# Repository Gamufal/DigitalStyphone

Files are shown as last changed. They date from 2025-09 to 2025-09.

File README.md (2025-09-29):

# Digital Stylophone

A microcontroller-based stylophone with recording and playback capabilities, built around the Raspberry Pi Pico. This project reimagines the classic analog instrument with modern digital features, including an OLED display and non-volatile memory for storing recorded tracks.

## Demo

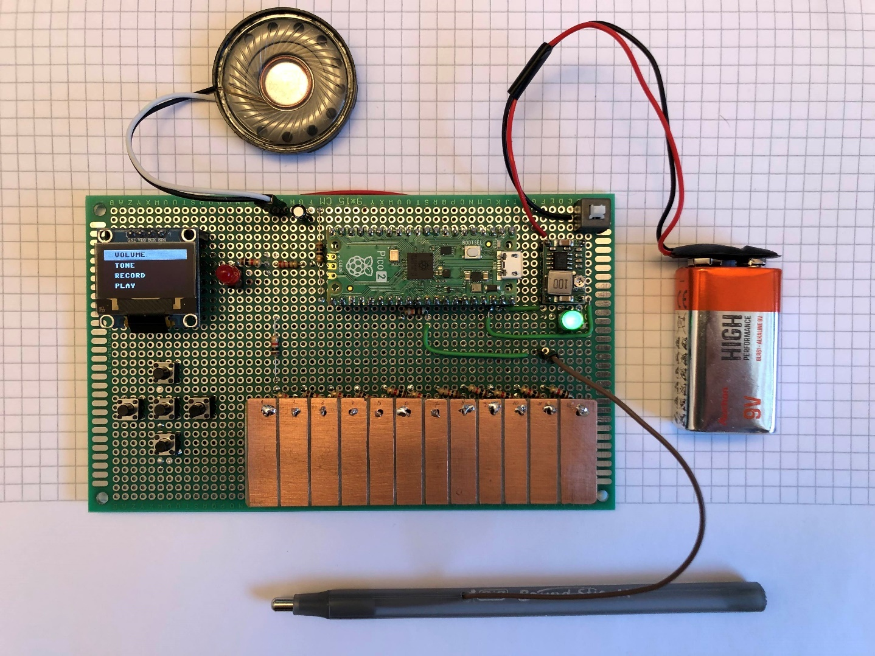
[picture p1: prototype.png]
Digital Stylophone


## Features

*   **Sound Generation:** Produces a square wave tone with a classic synthesizer sound.
*   **Multiple Octaves:** Three selectable octaves (low, middle, high).
*   **Volume Control:** Adjustable volume with 8 levels.
*   **Recording & Playback:** Record, save, and play back musical sequences.
*   **Persistent Memory:** Saves the recorded track and user settings (volume, octave) to a `settings.json` file on the device.
*   **OLED Display Interface:** A 128x64 SSD1306 OLED screen provides a menu-based interface for all functions.
*   **Tactile Controls:** 5-button navigation for intuitive menu control.
*   **Portable Design:** Powered by a 9V battery for on-the-go use.
*   **Raspberry Pi Pico Core:** Utilizes a Raspberry Pi Pico for all processing and hardware control.

## Hardware

### Components

| Component | Quantity |
|---|---|
| Raspberry Pi Pico | 1 |
| 5mm LED | 2 |
| 10Ω Resistor (1/4W) | 1 |
| 1kΩ Resistor (1/4W) | 21 |
| 10kΩ Resistor (1/4W) | 1 |
| 10uF Capacitor | 1 |
| 0.96" OLED Display | 1 |
| LM2596 Step-down Converter | 1 |
| 6x6mm Tactile Switch | 5 |
| Female Pin Headers | 5 |
| Latching Switch | 1 |
| 9V Battery | 1 |
| 1W 8Ohm Speaker | 1 |

### Schematic

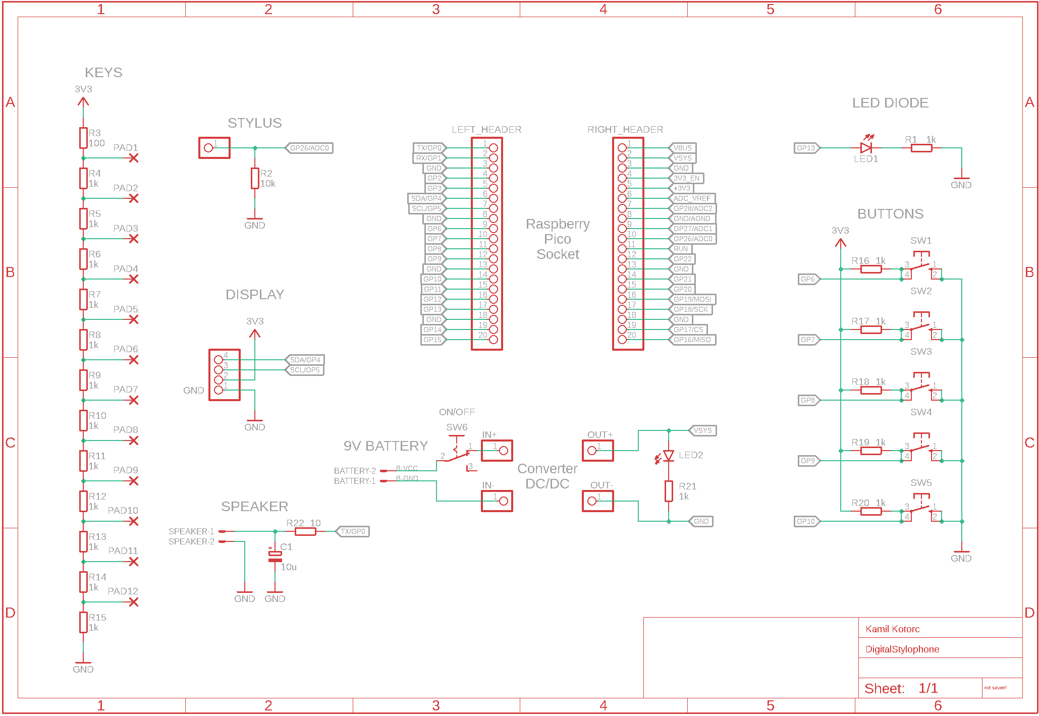
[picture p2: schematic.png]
Schematic


### PCB Design

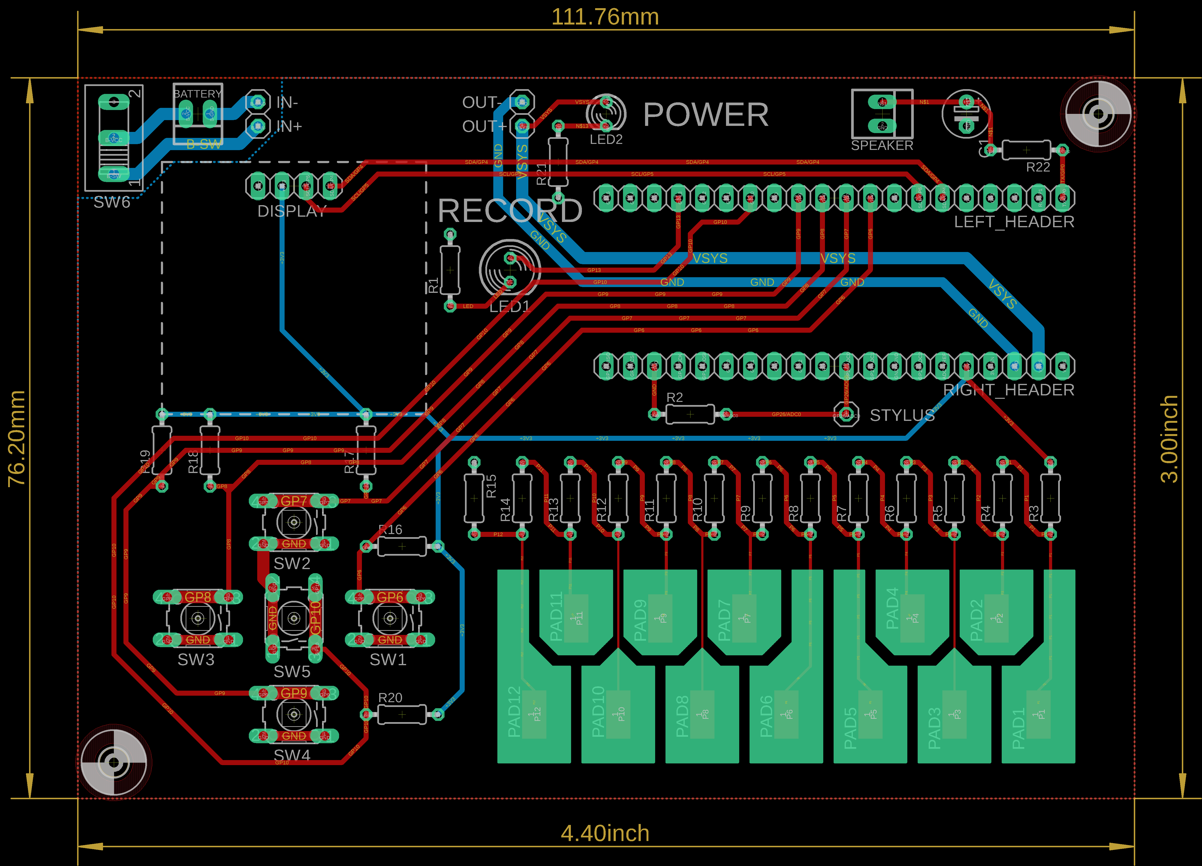
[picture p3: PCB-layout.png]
PCB Layout

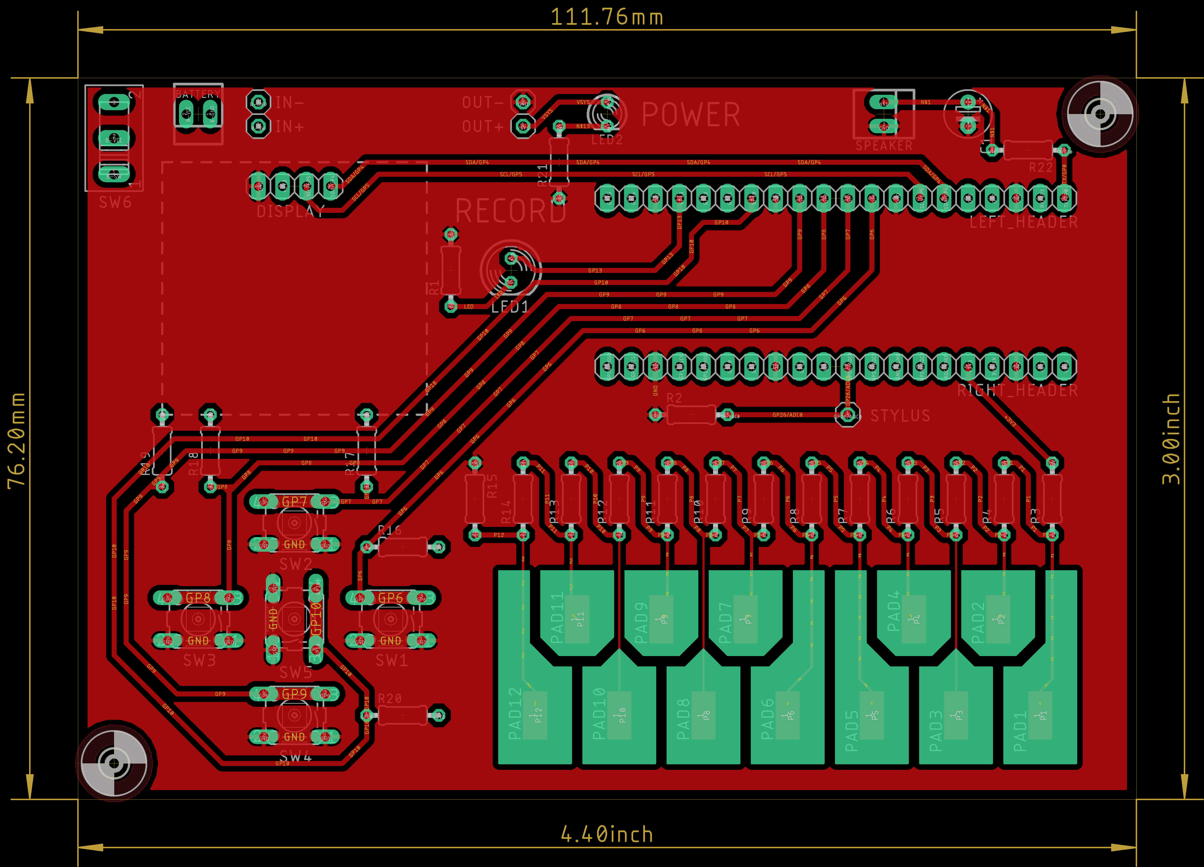
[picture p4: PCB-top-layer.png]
PCB_Top

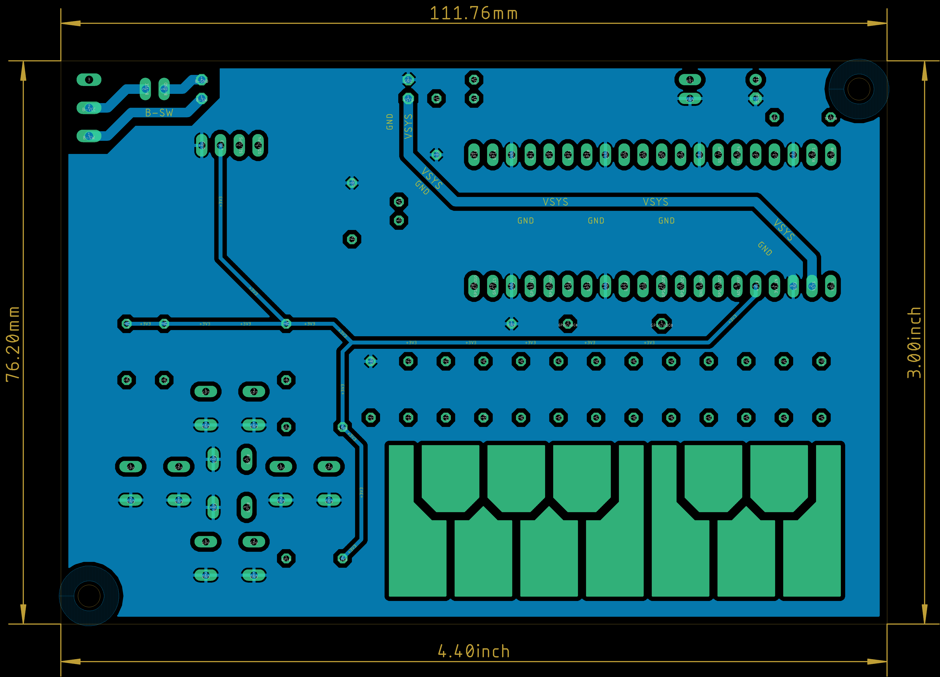
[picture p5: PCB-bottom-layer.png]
PCB_Bottom


### Manufacture Preview

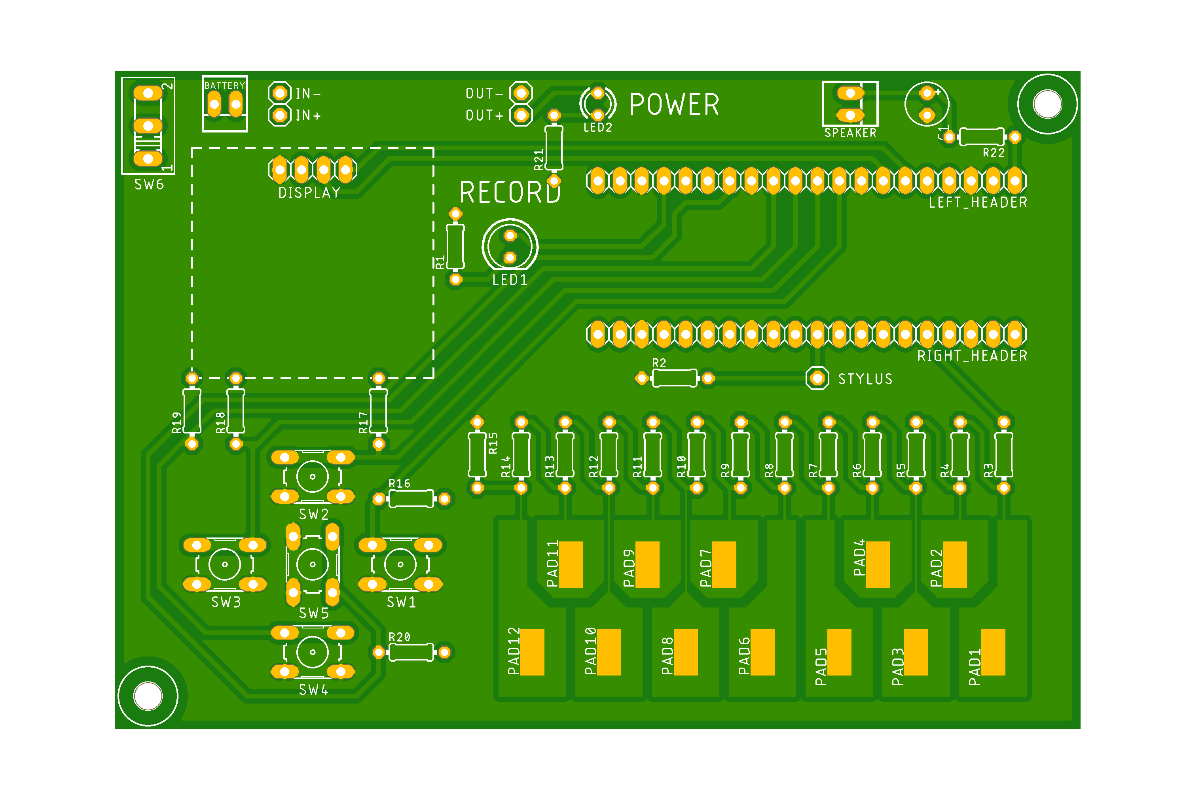
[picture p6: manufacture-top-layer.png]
Manufacture Top

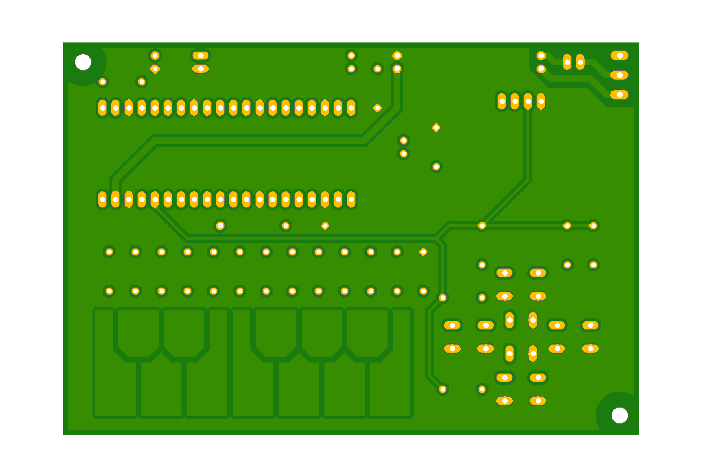
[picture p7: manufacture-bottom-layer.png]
Manufacture Bottom


### 3D Housing Model

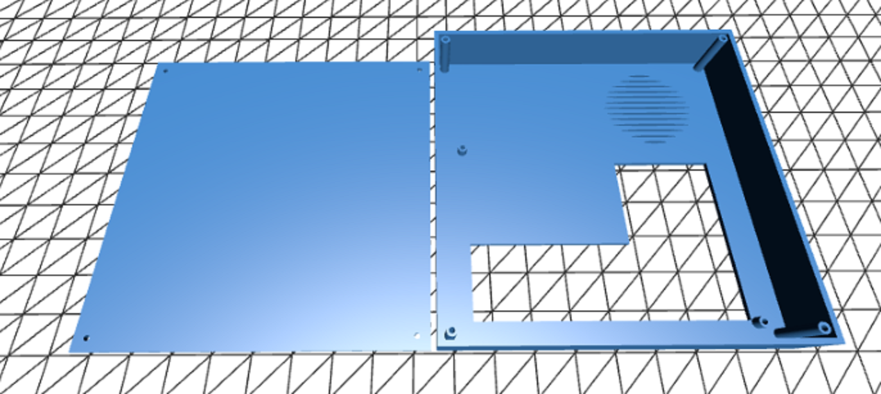
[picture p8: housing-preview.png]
Housing

A 3D-printed enclosure can also be made for the device. A model of the enclosure has been prepared for this purpose, and it is available as the `housing.stl` file.

## Software

### How it Works

The device is controlled by a MicroPython script (`main.py`) running on the Raspberry Pi Pico.

*   **Sound Generation:** The stylus's position on the resistive keyboard is read as an analog value by the Pico's ADC (Analog-to-Digital Converter). This value is then mapped to a specific musical note frequency. The sound is generated using PWM (Pulse Width Modulation) sent to a 1W speaker.

*   **UI & Menu:** A menu-driven interface is displayed on the 128x64 OLED screen. The user navigates the menu using a 5-button keypad. The available options are Volume, Tone (Octave), Record, and Play.

*   **Recording & Playback:** The recording function captures a sequence of notes and their timings. It records pairs of `(frequency, timestamp)` to a list. The playback function iterates through the recorded list, playing back the notes with the correct timing.

*   **Persistence:** The recorded song, as well as the volume and tone settings, are saved to a `settings.json` file in the Pico's flash memory. This allows the device to retain settings and recordings between power cycles.

### Installation

1.  **Install MicroPython:** If you haven't already, install MicroPython on your Raspberry Pi Pico. You can find the official instructions [here](https://www.raspberrypi.com/documentation/microcontrollers/micropython.html).

2.  **Install `ssd1306.py`:** The OLED display requires the `ssd1306.py` library. You can find it [here](https://github.com/micropython/micropython/blob/master/drivers/display/ssd1306.py) and save it to your Pico.

3.  **Upload the Software:** Copy the `main.py` file to your Raspberry Pi Pico. The easiest way to do this is by using an IDE like [Thonny](https://thonny.org/), which has a simple interface for managing files on a MicroPython device.

## User Guide

### Controls

| Control | Function |
|---|---|
| Up/Down Buttons | Navigate through the main menu. |
| Left/Right Buttons | Decrease/increase the volume or tone (octave). |
| OK Button | Select a menu option; start/stop recording or playback. |
| Stylus | Play notes by touching the corresponding keys. |

### Operation

1.  **Power On:** Connect a 9V battery and flip the power switch. The green LED will light up, and the main menu will appear on the OLED display.
2.  **Play Music:** Simply touch the stylus to any of the metal keys to play a note.
3.  **Navigate Menu:** Use the **Up** and **Down** buttons to highlight a menu option.
4.  **Select Option:** Press the **OK** button to enter the selected menu (Volume, Tone, Record, or Play).
5.  **Adjust Volume/Tone:** In the Volume or Tone menus, use the **Left** and **Right** buttons to make adjustments. Press **Up** or **Down** to exit and save.
6.  **Record:** Select "RECORD" from the main menu and press **OK**. Press **OK** again to start recording. The red LED will blink. Play your tune, and press **OK** to stop. The recording will be saved automatically.
7.  **Playback:** Select "PLAY" from the main menu and press **OK**. Press **OK** again to start playback of the last recorded track. The red LED will stay lit during playback.

## Troubleshooting

| Symptom | Possible Cause | Suggested Solution |
|---|---|---|
| Screen works, but the green power LED is off. | The green LED is burnt out. | Replace the green LED. |
| The green power LED is on, but the screen is blank. | The OLED display is damaged or disconnected. | Check the display's connections. If the problem persists, replace the display module. |
| Nothing works (no screen, no LEDs). | The 9V battery is dead. | Replace the 9V battery. |
| The screen and LEDs work, but there is no sound. | The speaker is damaged or disconnected. | Check the speaker wiring. If the problem persists, replace the speaker. |

## Future Improvements

*   **Enhanced Sound Engine:**
    *   Add a vibrato effect using a Low-Frequency Oscillator (LFO).
*   **Connectivity:**
    *   Add MIDI output via USB, allowing the stylophone to function as a MIDI controller.
*   **Code Refinements:**
    *   Refactor the code for better efficiency, especially the recording and display update logic.

## License

This project is licensed under the MIT License. See the `LICENSE` file for details.

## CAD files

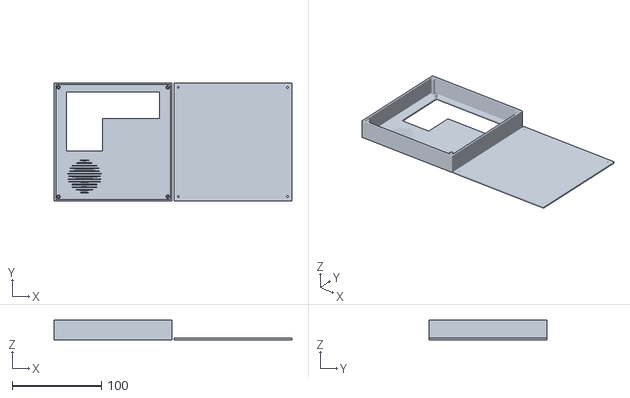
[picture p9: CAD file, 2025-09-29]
housing.stl
266.0 x 132.0 x 22.0

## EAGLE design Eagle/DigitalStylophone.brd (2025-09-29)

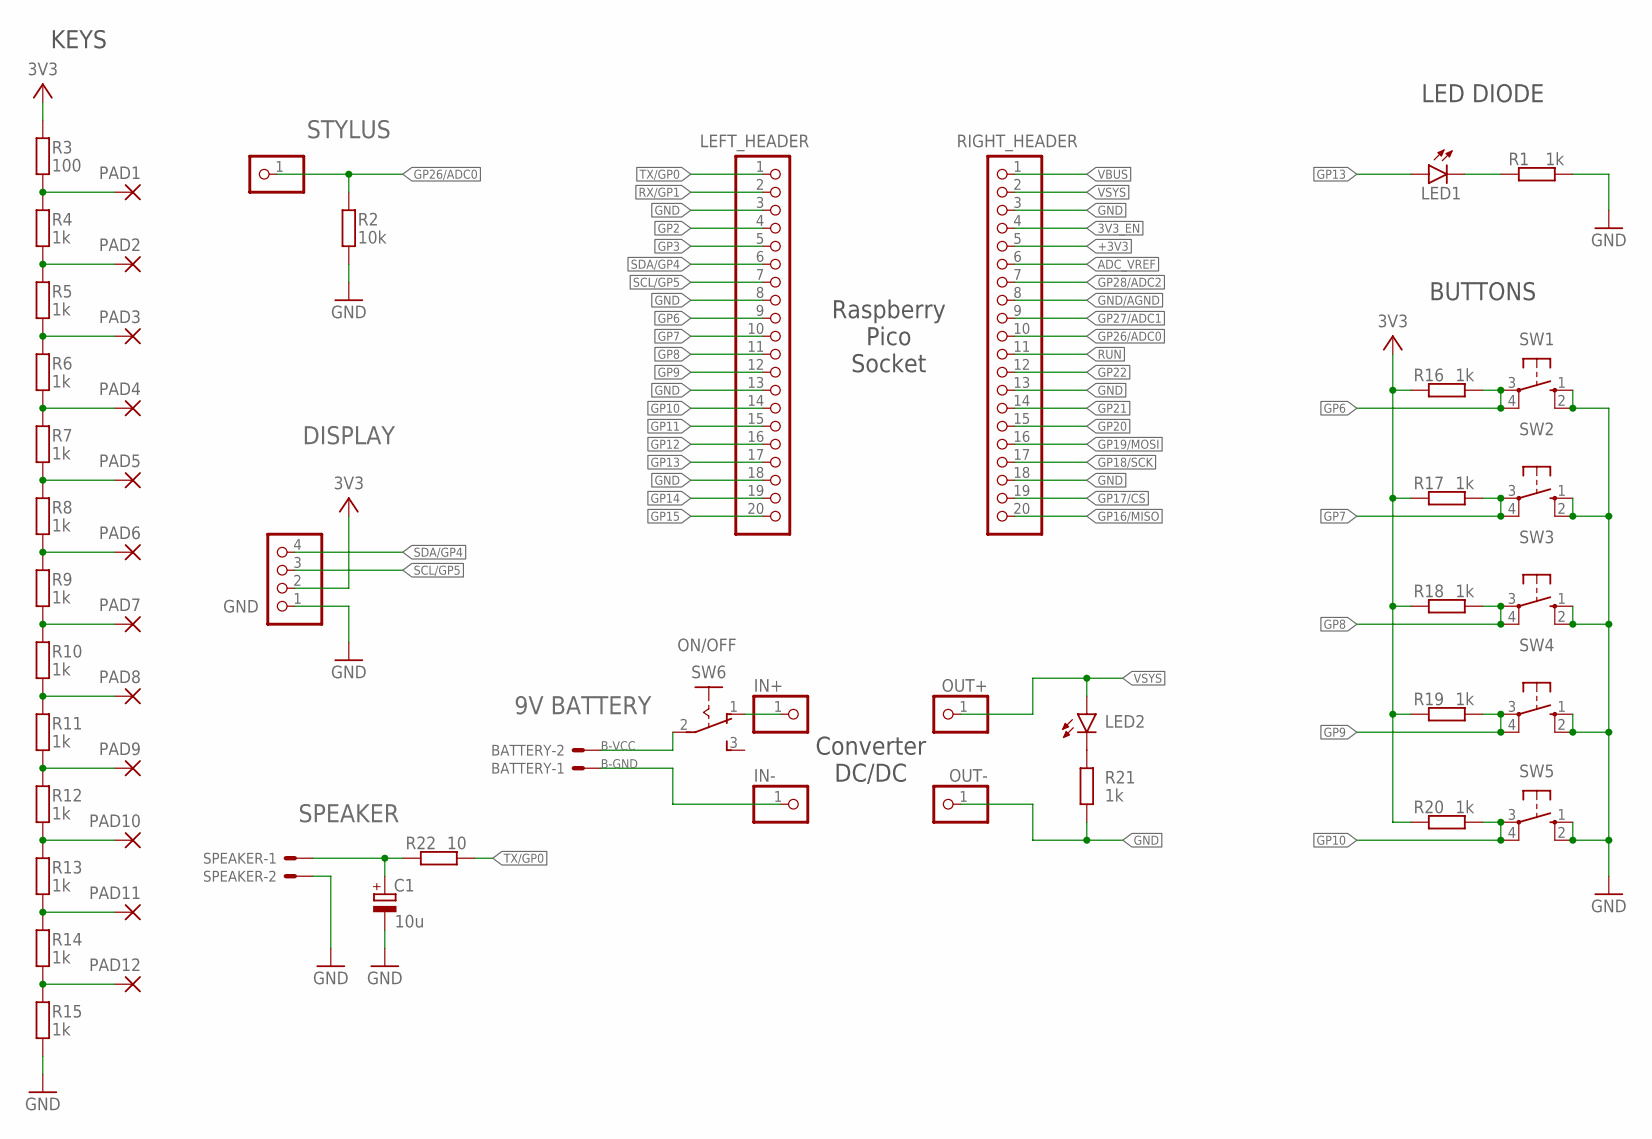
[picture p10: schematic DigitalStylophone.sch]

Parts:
BATTERY: 9V BATTERY; 22-23-2021
C1: 10u; E2,5-5
DISPLAY: GND; 1X04
IN+: PINHD-1X1; 1X01
IN-: PINHD-1X1; 1X01
LED1: LED5MM
LED2: LED3MM
LEFT_HEADER: PINHD-1X20; 1X20
OUT+: PINHD-1X1; 1X01
OUT-: PINHD-1X1; 1X01
PAD1, PAD2, PAD3, PAD4, PAD5, PAD6, PAD7, PAD8, PAD9, PAD10, PAD11, PAD12: SMD5; SMD2,54-5,08
R1, R4, R5, R6, R7, R8, R9, R10, R11, R12, R13, R14, R15, R16, R17, R18, R19, R20, R21: 1k; 0204/7
R2: 10k; 0204/7
R3: 100; 0204/7
R22: 10; 0204/7
RIGHT_HEADER: PINHD-1X20; 1X20
SPEAKER: SPEAKER; 22-23-2021
STYLUS: PINHD-1X1; 1X01
SW1, SW2, SW3, SW4, SW5: 10-XX; B3F-10XX
SW6: ON/OFF; 255SB

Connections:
3V3_EN: RIGHT_HEADER.4
+3V3: DISPLAY.2, R3.2, R16.2, R17.2, R18.2, R19.2, R20.2, RIGHT_HEADER.5
ADC_VREF: RIGHT_HEADER.6
B-GND: BATTERY.1, IN-.1
B-SW: IN+.1, SW6.1 (O)
B-VCC: BATTERY.2, SW6.2
GND: C1.-, DISPLAY.1, LEFT_HEADER.3, LEFT_HEADER.8, LEFT_HEADER.13, LEFT_HEADER.18, OUT-.1, R1.1, R2.1, R15.1, R21.1, RIGHT_HEADER.3, RIGHT_HEADER.13, RIGHT_HEADER.18, SPEAKER.2, SW1.1 (S), SW1.2 (S1), SW2.1 (S), SW2.2 (S1), SW3.1 (S), SW3.2 (S1), SW4.1 (S), SW4.2 (S1), SW5.1 (S), SW5.2 (S1)
GND/AGND: RIGHT_HEADER.8
GP2: LEFT_HEADER.4
GP3: LEFT_HEADER.5
GP6: LEFT_HEADER.9, R16.1, SW1.3, SW1.4 (P1)
GP7: LEFT_HEADER.10, R17.1, SW2.3, SW2.4 (P1)
GP8: LEFT_HEADER.11, R18.1, SW3.3, SW3.4 (P1)
GP9: LEFT_HEADER.12, R19.1, SW4.3, SW4.4 (P1)
GP10: LEFT_HEADER.14, R20.1, SW5.3, SW5.4 (P1)
GP11: LEFT_HEADER.15
GP12: LEFT_HEADER.16
GP13: LED1.A, LEFT_HEADER.17
GP14: LEFT_HEADER.19
GP15: LEFT_HEADER.20
GP16/MISO: RIGHT_HEADER.20
GP17/CS: RIGHT_HEADER.19
GP18/SCK: RIGHT_HEADER.17
GP19/MOSI: RIGHT_HEADER.16
GP20: RIGHT_HEADER.15
GP21: RIGHT_HEADER.14
GP22: RIGHT_HEADER.12
GP26/ADC0: R2.2, RIGHT_HEADER.10, STYLUS.1
GP27/ADC1: RIGHT_HEADER.9
GP28/ADC2: RIGHT_HEADER.7
LED: LED1.K (C), R1.2
unnamed: C1.+, R22.2, SPEAKER.1
unnamed: LED2.K (C), R21.2
P1: PAD1.1, R3.1, R4.2
P2: PAD2.1, R4.1, R5.2
P3: PAD3.1, R5.1, R6.2
P4: PAD4.1, R6.1, R7.2
P5: PAD5.1, R7.1, R8.2
P6: PAD6.1, R8.1, R9.2
P7: PAD7.1, R9.1, R10.2
P8: PAD8.1, R10.1, R11.2
P9: PAD9.1, R11.1, R12.2
P10: PAD10.1, R12.1, R13.2
P11: PAD11.1, R13.1, R14.2
P12: PAD12.1, R14.1, R15.2
RUN: RIGHT_HEADER.11
RX/GP1: LEFT_HEADER.2
SCL/GP5: DISPLAY.3, LEFT_HEADER.7
SDA/GP4: DISPLAY.4, LEFT_HEADER.6
TX/GP0: LEFT_HEADER.1, R22.1
VBUS: RIGHT_HEADER.1
VSYS: LED2.A, OUT+.1, RIGHT_HEADER.2

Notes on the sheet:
Raspberry Pico Socket
KEYS
LED DIODE
BUTTONS
Converter DC/DC

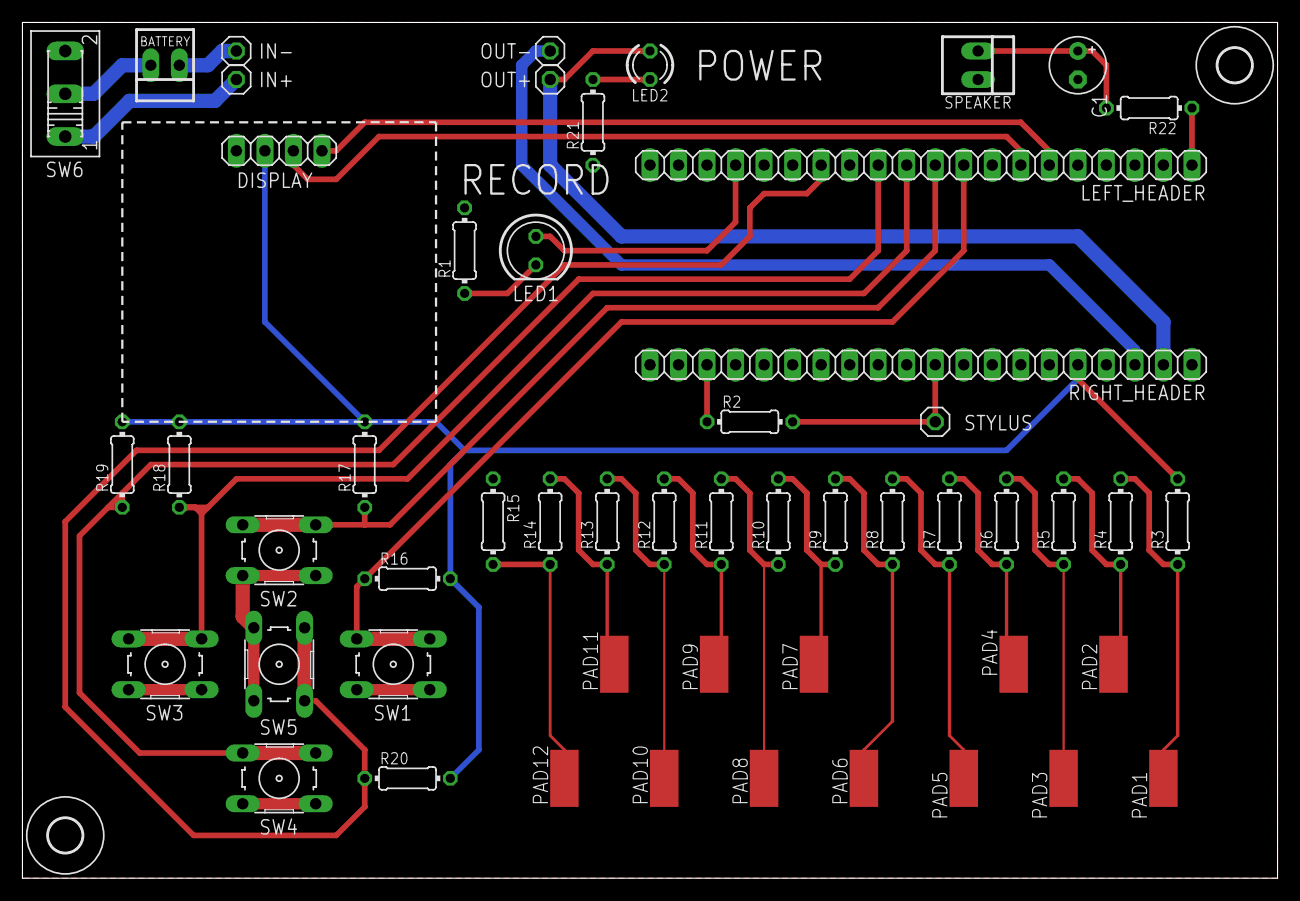
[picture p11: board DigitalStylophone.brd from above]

Board: 2 copper layers, 111.8 x 76.2 mm, 55 parts (0 on the bottom side), 31 nets.

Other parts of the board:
U$1, U$2: 3,0

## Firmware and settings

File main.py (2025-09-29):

# Software for Digital Stylophone project
# Made by Gamufal
# Version: 25.9.1

from machine import Pin, ADC, I2C, PWM
import ssd1306
import json
from time import sleep, time, ticks_ms, ticks_diff

# Initialization of OLED Display (128x64)
i2c = I2C(0, sda=Pin(4), scl=Pin(5), freq=400000)
display = ssd1306.SSD1306_I2C(128, 64, i2c)

# LED diode initialization
led = Pin(13, Pin.OUT)

# Buttons initialization 
btn_down  = Pin(6,  Pin.IN, Pin.PULL_UP)
btn_up    = Pin(8,  Pin.IN, Pin.PULL_UP)
btn_right = Pin(7,  Pin.IN, Pin.PULL_UP)
btn_left  = Pin(9,  Pin.IN, Pin.PULL_UP)
btn_ok    = Pin(10, Pin.IN, Pin.PULL_UP)

# ADC Initialization for stylus 
adc = ADC(Pin(26))
adc_thresholds = [4500, 9000, 13000, 17000, 20000, 24000, 29000, 34000, 39000, 46000, 54000, 64000]

# PWM Initialization for the speaker
spk = PWM(Pin(16))
spk.duty_u16(0)

# Three sets of notes:
lower_octave  = [131, 139, 147, 156, 165, 175, 185, 196, 208, 220, 233, 247]
middle_octave = [261, 277, 293, 311, 329, 349, 369, 392, 415, 440, 466, 493]
higher_octave = [523, 554, 587, 622, 659, 698, 739, 784, 830, 880, 932, 987]

# Global settings
volume = 4   # 1-8
tone = 2     # 1-3
recording = []  # (freq, timestamp), ...

# Saves a single setting to a JSON file
def save_single_setting(key, value):
    try:
        with open("settings.json", "r") as f:
            settings = json.load(f)
    except (OSError, ValueError):
        settings = {}
    settings[key] = value
    with open("settings.json", "w") as f:
        json.dump(settings, f)
    print(f"Saved {key}: {value}")

# Loads saved settings from a JSON file
def load_settings():
    global volume, tone, recording
    try:
        with open("settings.json", "r") as f:
            settings = json.load(f)
            volume = settings.get("volume", 4)
            tone = settings.get("tone", 2) 
            recording = settings.get("recording", [])  
        print("Settings loaded!")
    except Exception as e:
        print("No settings found, using defaults.", e)

# Returns the index of the note based on the ADC value
def get_note_index(adc_val):
    idx = -1
    for i in range(len(adc_thresholds)):
        if adc_val >= adc_thresholds[i]:
            idx = i
        else:
            break
    return idx if idx != -1 else None

# Retrieves the note frequency from the index and currently selected octave
def get_note_from_index(idx):
    global tone
    if tone == 1:
        return lower_octave[idx]
    elif tone == 2:
        return middle_octave[idx]
    elif tone == 3:
        return higher_octave[idx]

# Updates the speaker output in real time based on the ADC reading
def update_live_audio():
    adc_val = adc.read_u16()
    idx = get_note_index(adc_val)
    if idx is not None:
        freq = get_note_from_index(idx)
        spk.freq(freq)
        spk.duty_u16(volume * 4096)
    else:
        spk.duty_u16(0)

# Displays the main menu
def display_menu(selected_item):
    menu_items = ["VOLUME", "TONE", "RECORD", "PLAY"]
    display.fill(0)
    for i, item in enumerate(menu_items):
        y = i * 16
        if i == selected_item:
            display.fill_rect(0, y, 128, 16, 1)  
            display.text(item, 16, y + 4, 0)      
        else:
            display.text(item, 16, y + 4, 1)      
    display.show()

# Handles volume adjustment
def volume_menu():
    global volume
    display.fill(0)
    display.text("VOLUME", 16, 30, 1)
    display.text(str(volume), 104, 30, 1)
    bar_width = int(volume * 96 / 8)
    display.fill_rect(16, 45, bar_width, 10, 1)
    display.show()
    while True:
        update_live_audio()
        if btn_left.value() == 0 and volume > 1:
            volume -= 1
            display.fill(0)
            display.text("VOLUME", 16, 30, 1)
            display.text(str(volume), 104, 30, 1)
            bar_width = int(volume * 96 / 8)
            display.fill_rect(16, 45, bar_width, 10, 1)
            display.show()
            sleep(0.2)
        elif btn_right.value() == 0 and volume < 8:
            volume += 1
            display.fill(0)
            display.text("VOLUME", 16, 30, 1)
            display.text(str(volume), 104, 30, 1)
            bar_width = int(volume * 96 / 8)
            display.fill_rect(16, 45, bar_width, 10, 1)
            display.show()
            sleep(0.2)
        elif btn_up.value() == 0 or btn_down.value() == 0:
            save_single_setting("volume", volume)
            while btn_up.value() == 0 or btn_down.value() == 0:      
                sleep(0.05)
            return
        sleep(0.05)

# Handles octaves selection
def tone_menu():
    global tone
    display.fill(0)
    display.text("TONE", 16, 30, 1)
    display.text(str(tone), 104, 30, 1)
    bar_width = int(tone * 96 / 3)  
    display.fill_rect(16, 45, bar_width, 10, 1)
    display.show()
    while True:
        update_live_audio()
        if btn_left.value() == 0 and tone > 1:
            tone -= 1
            display.fill(0)
            display.text("TONE", 16, 30, 1)
            display.text(str(tone), 104, 30, 1)
            bar_width = int(tone * 96 / 3)  
            display.fill_rect(16, 45, bar_width, 10, 1)
            display.show()
            sleep(0.2)
        elif btn_right.value() == 0 and tone < 3:
            tone += 1
            display.fill(0)
            display.text("TONE", 16, 30, 1)
            display.text(str(tone), 104, 30, 1)
            bar_width = int(tone * 96 / 3)  
            display.fill_rect(16, 45, bar_width, 10, 1)
            display.show()
            sleep(0.2)
        elif btn_up.value() == 0 or btn_down.value() == 0:
            save_single_setting("tone", tone)
            while btn_up.value() == 0 or btn_down.value() == 0:
                sleep(0.05)
            return
        sleep(0.05)

# Records a sequence of note frequencies
def record_menu():
    global recording
    display.fill(0)
    display.text("RECORD", 16, 30, 1)
    display.text("OK = start", 16, 42, 1)
    display.show()
    while True:
        update_live_audio()
        if btn_ok.value() == 0:
            while btn_ok.value() == 0:
                sleep(0.05)
            display.fill(0)
            display.text("Recording...", 16, 30, 1)
            display.show()
            print("Waiting for first note...")
            while True:
                adc_val = adc.read_u16()
                idx = get_note_index(adc_val)
                if idx is not None:
                    break
                sleep(0.05)
            recording = []
            start_time = ticks_ms()
            last_led_toggle = ticks_ms()
            while True:
                adc_val = adc.read_u16()
                idx = get_note_index(adc_val)
                if idx is None:
                    freq = 0
                    spk.duty_u16(0)
                else:
                    freq = get_note_from_index(idx)
                    spk.freq(freq)
                    spk.duty_u16(volume * 4096)
                    print("Recording note:", freq)
                current_time = ticks_diff(ticks_ms(), start_time)
                recording.append((freq, current_time))
                if ticks_diff(ticks_ms(), last_led_toggle) >= 500:
                    led.value(not led.value())
                    last_led_toggle = ticks_ms()
                if btn_ok.value() == 0:
                    while btn_ok.value() == 0:
                        sleep(0.05)
                    break
                sleep(0.01)
            spk.duty_u16(0)
            led.off()
            save_single_setting("recording", recording)
            display.fill(0)
            display.text("Done", 16, 30, 1)
            display.show()
            sleep(1)
            return
        elif btn_up.value() == 0 or btn_down.value() == 0:
            while btn_up.value() == 0 or btn_down.value() == 0:
                sleep(0.05)
            return
        sleep(0.05)

# Plays back a previously recorded track
def play_menu():
    display.fill(0)
    display.text("PLAY", 16, 30, 1)
    display.text("OK = play", 16, 42, 1)
    display.show()
    while True:
        update_live_audio()
        if btn_ok.value() == 0:
            while btn_ok.value() == 0:
                sleep(0.05)
            display.fill(0)
            display.text("Playing...", 16, 30, 1)
            display.show()
            led.on()
            start_play = ticks_ms()
            for i in range(len(recording) - 1):
                freq, t = recording[i]
                next_freq, next_t = recording[i+1]
                if freq != 0:
                    spk.freq(freq)
                    spk.duty_u16(volume * 4096)
                    print("Playing note:", freq, "for", (next_t - t)/1000, "s")
                else:
                    spk.duty_u16(0)
                    print("Playing silence for", (next_t - t)/1000, "s")
                delay_ms = next_t - t
                sleep(delay_ms / 1000)
            spk.duty_u16(0)
            led.off()
            display.fill(0)
            display.text("OK = play", 16, 30, 1)
            display.show()
            return
        elif btn_up.value() == 0 or btn_down.value() == 0:
            while btn_up.value() == 0 or btn_down.value() == 0:
                sleep(0.05)
            return
        sleep(0.05)

# Main loop
def main():
    selected_item = 0
    while True:
        display_menu(selected_item)
        update_live_audio()
        if btn_down.value() == 0:
            selected_item = (selected_item + 1) % 4
            sleep(0.2)
        if btn_up.value() == 0:
            selected_item = (selected_item - 1) % 4
            sleep(0.2)
        if btn_ok.value() == 0:
            while btn_ok.value() == 0:
                sleep(0.05)
            if selected_item == 0:
                volume_menu()
            elif selected_item == 1:
                tone_menu()
            elif selected_item == 2:
                record_menu()
            elif selected_item == 3:
                play_menu()
        sleep(0.05)

# Program start
load_settings()
main()

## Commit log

2025-09-29 Added eagle files
    [DigitalStylophone.brd, DigitalStylophone.sch]
2025-09-29 Added pico software
2025-09-29 Added image of a prototype
2025-09-29 adding stylophone case
    [housing.stl]
2025-09-29 added stl preview
